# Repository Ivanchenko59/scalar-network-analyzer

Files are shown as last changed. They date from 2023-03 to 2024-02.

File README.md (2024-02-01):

# scalar-network-analyzer

## Description
This project was created as my graduating project at the university.
Scalar network analyzer developed to measure frequency response of filters, amplifiers, transmission lines or other frequency-dependent circuits.

## About the project

## Demo video

## Block scheme 

The basic principle of operation of a scalar analyzer is to measure the amplitude of a transmission wave through a device under test (DUT). 
Such an analyzer contains both a signal source and a receiver. The source is used to obtain a known signal, while the receiver is used to 
determine changes in this signal caused by the circuit under test.

зображення

The main component of the device is a signal generator SI5351 with 2 independent outputs, which has a square wave output signal, so it is 
impossible to use such a signal in a circuit with a broadband detector. So this was solved by using the architecture of a superheterodyne receiver.

The basic idea of a superheterodyne is a linear transfer of the spectrum to a specific frequency. This is achieved by synchronously changing the 
RF frequency (which is fed to the DUT) and the local oscillator (LO) frequency.

Next, the signal is filtered using piezoceramic filters at 455 kHz (this frequency was chosen because there are many cheap filters for this frequency) 
and amplified to use the full dynamic range of the logarithmic amplifier. After filtration, the signal will have a sinusoidal waveform.

The signal is fed to a logarithmic amplifier, the output of which is a constant voltage proportional to the power in dBm. The signal is then measured using an ADC
controller, processed with MCU and transmitted data to a computer via USB.

## Schematic

зображення

зображення

зображення

зображення

зображення

## Hardware
A 4-layer printed circuit board was designed and manufactured. I created two impedance profiles of 90 ohms for the USB interface and 50 ohms for high-frequency 
signal transmission lines, since the device must operate in systems with such wave impedance.

зображення

зображення

зображення

## Software
### CubeMX Connectivity 


## PC Application

## Testing
The low-pass at 12 MHz LC filter was tested. The ideal characteristic in LTSpice is shown below.

зображення

Measured characteristic with the use of the scalar analyzer is shown below. 

зображення

Also, an 8 MHz quartz resonator was measured.

зображення

Below is a characteristic of a piezoceramic bandpass filter with unknown characteristics (similar to the one used in the device circuitry).
It should be added that the impedance of the filter (1500 ohms) is not matched to the device (50 ohms), which causes noticeable ripples in the passband.

зображення

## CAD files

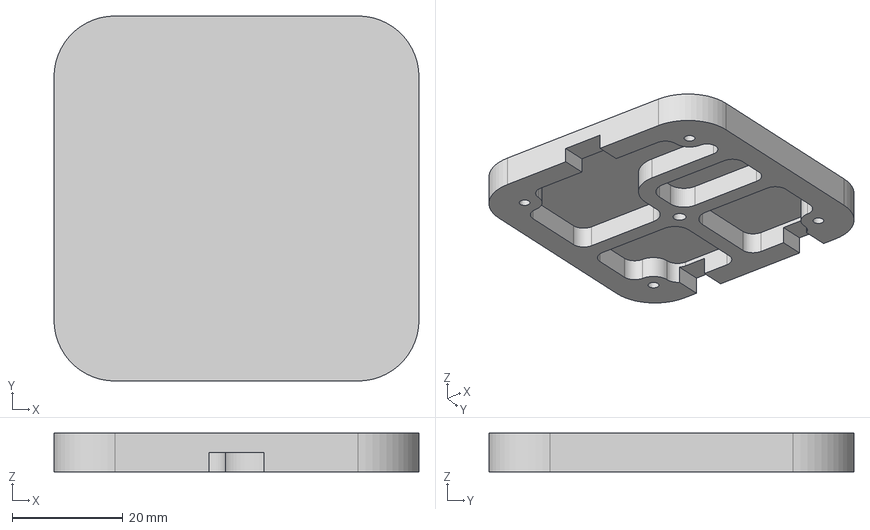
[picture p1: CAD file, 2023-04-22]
3dmodel/Top case.step
66.0 x 66.0 x 7.00 mm

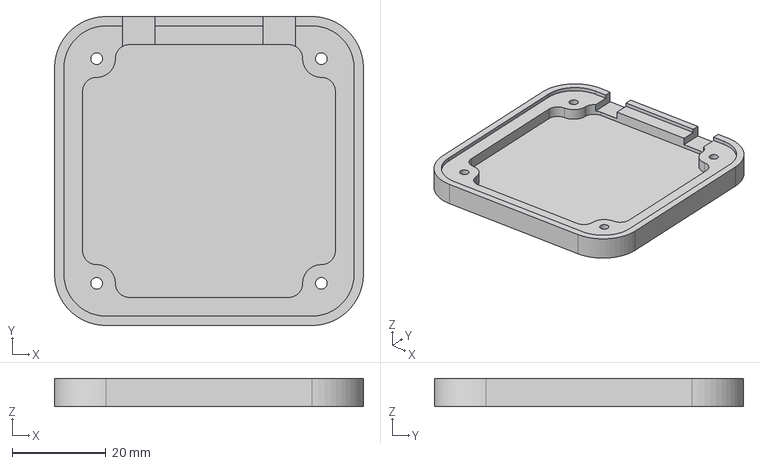
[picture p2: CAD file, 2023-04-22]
3dmodel/Bottom case.step
66.0 x 66.0 x 6.00 mm

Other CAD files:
3dmodel/Bottom case.f3d
3dmodel/Top case.f3d

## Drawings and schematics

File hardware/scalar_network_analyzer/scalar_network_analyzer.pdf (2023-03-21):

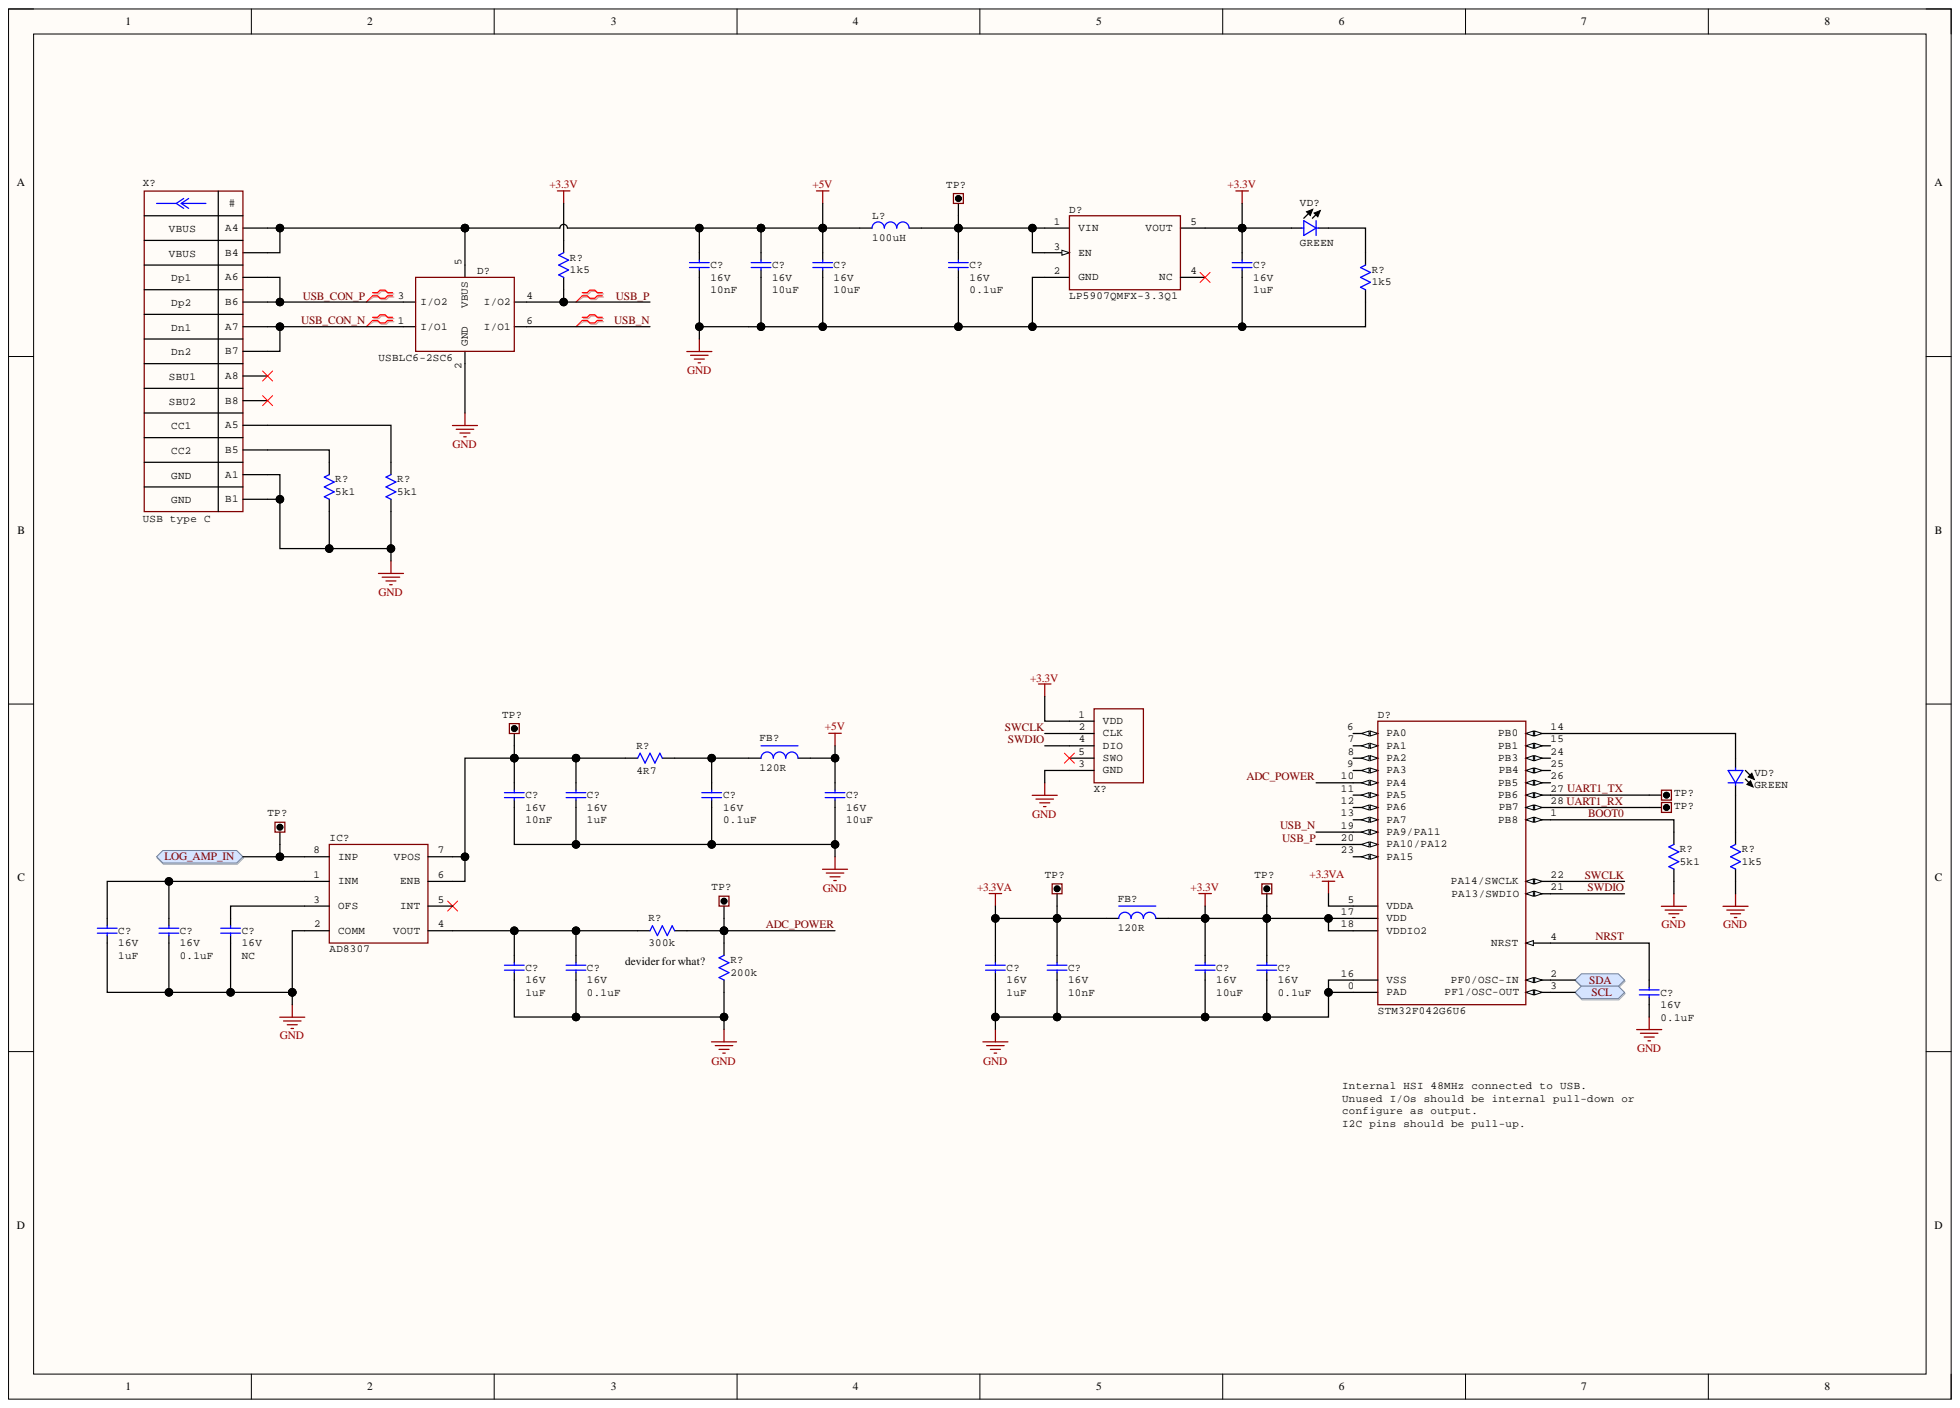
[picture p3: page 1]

VBUS | B4

SBU1 | A8

SBU2 | B8

GND | A1

GND | B1

Internal HSI 48MHz connected to USB.
Unused I/Os should be internal pull-down or
configure as output.
I2C pins should be pull-up.

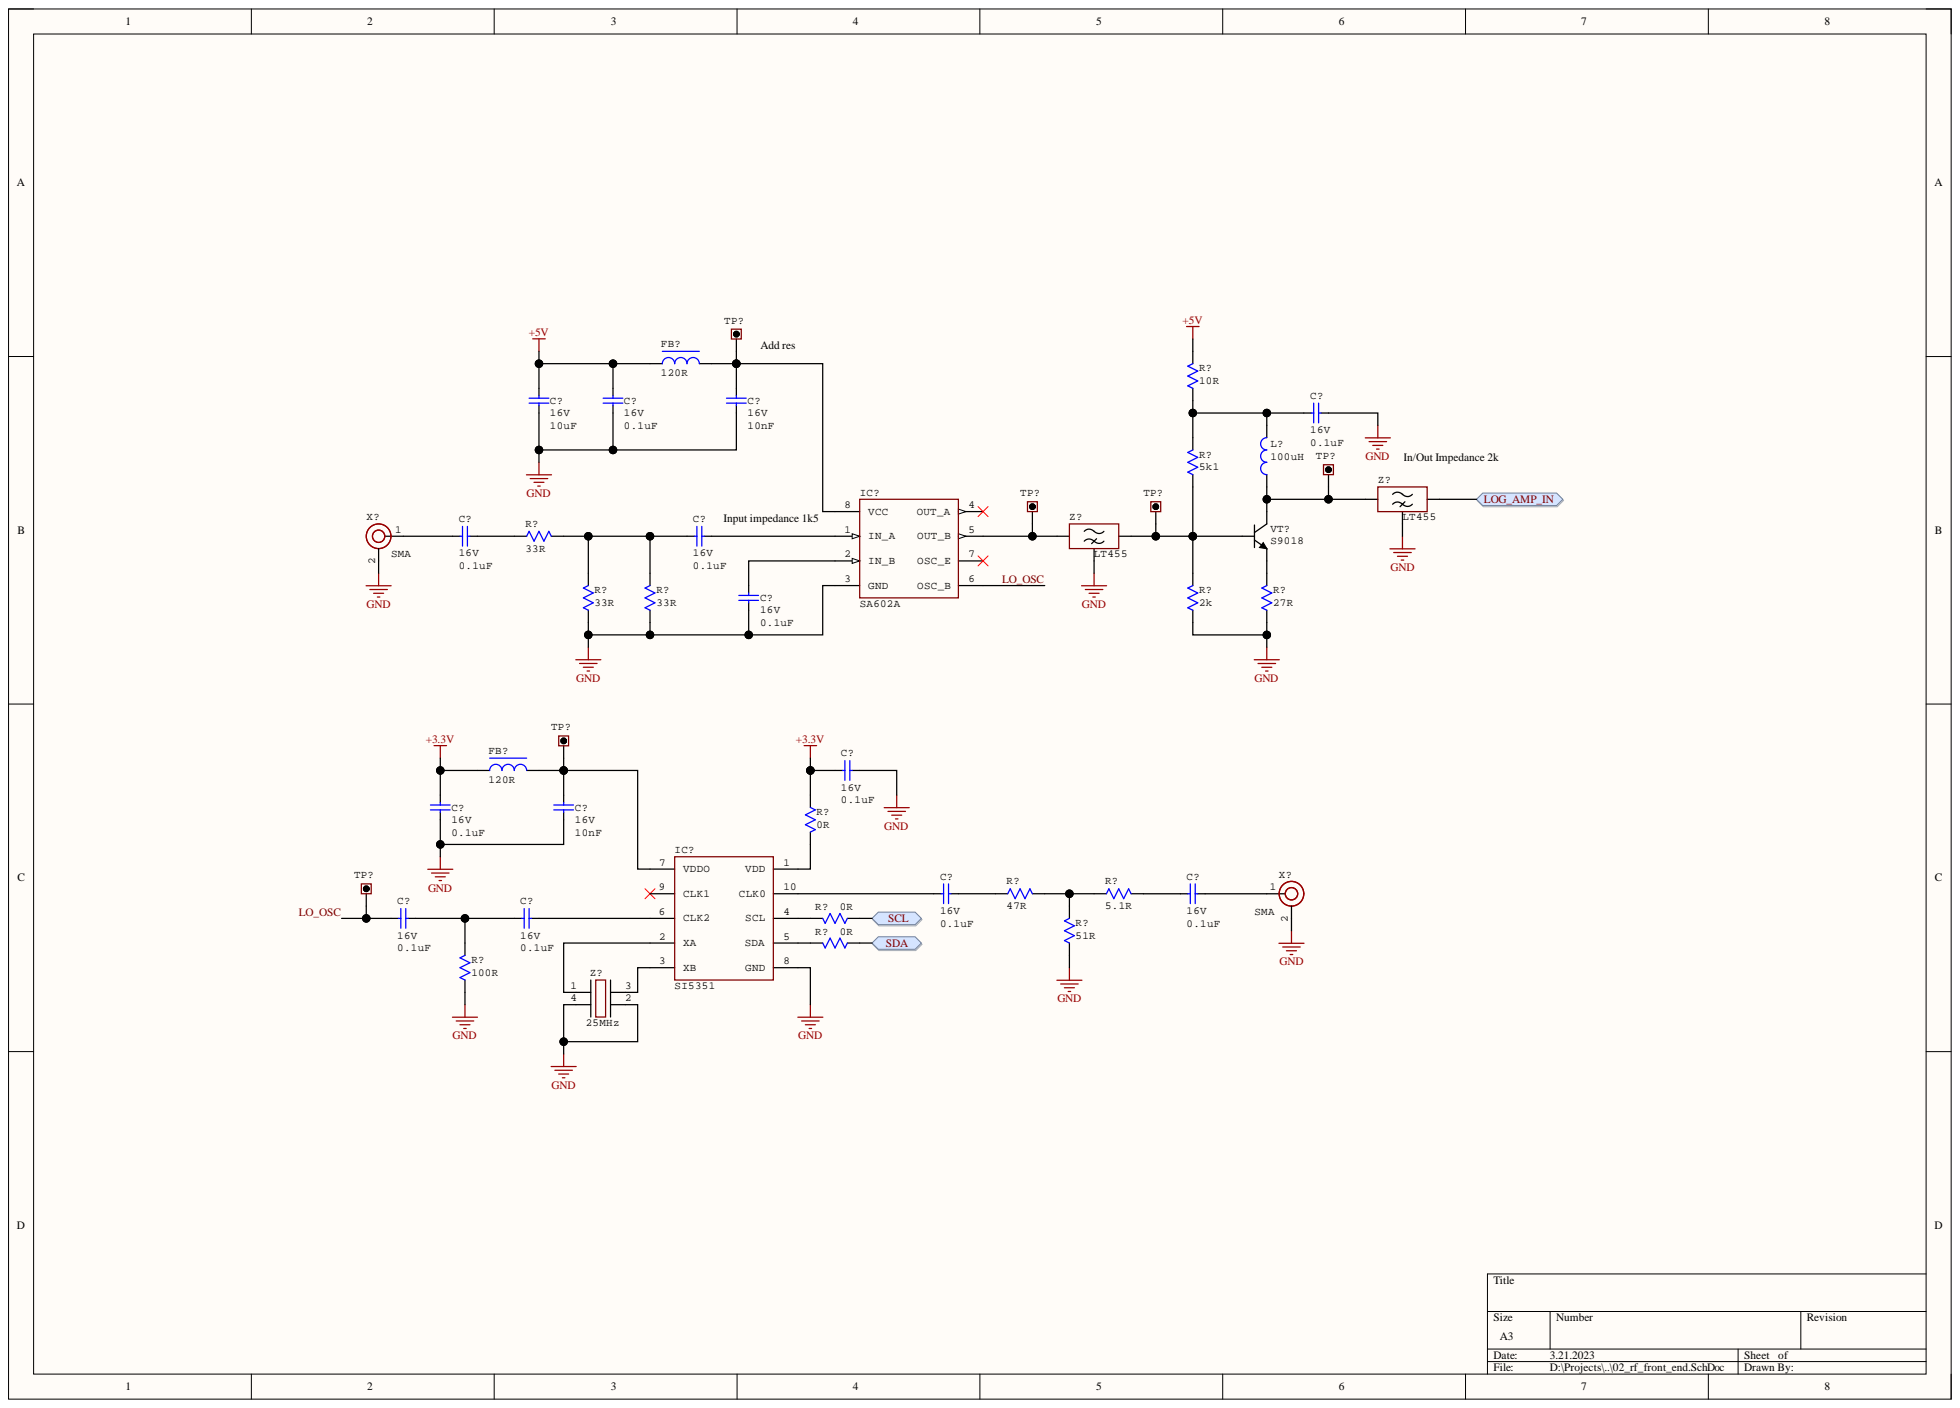
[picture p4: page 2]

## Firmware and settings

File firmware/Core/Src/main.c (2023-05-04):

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
/* Includes ------------------------------------------------------------------*/
#include "main.h"
#include "adc.h"
#include "dma.h"
#include "i2c.h"
#include "usart.h"
#include "usb_device.h"
#include "gpio.h"

/* USER CODE BEGIN Includes */
#include "usbd_cdc_if.h"
#include "si5351.h"

#include "device.h"
/* USER CODE END Includes */

/* USER CODE BEGIN PD */
#define VREFINT_CAL_ADDR	0x1FFFF7BA
#define VREFINT_CAL ((uint16_t*) VREFINT_CAL_ADDR)
/* USER CODE END PD */


/* USER CODE BEGIN PV */
const int32_t correction = 0;
volatile uint32_t new_time = 0;

//volatile uint32_t Vdd = 0;
/* USER CODE END PV */

void SystemClock_Config(void);
/**
  * @brief  The application entry point.
  * @retval int
  */
int main(void)
{
  /* MCU Configuration--------------------------------------------------------*/

  /* Reset of all peripherals, Initializes the Flash interface and the Systick. */
  HAL_Init();

  /* Configure the system clock */
  SystemClock_Config();

  /* Initialize all configured peripherals */
  MX_GPIO_Init();
  MX_I2C1_Init();
  MX_USB_DEVICE_Init();
  MX_USART1_UART_Init();
  MX_DMA_Init();
  MX_ADC_Init();
  /* USER CODE BEGIN 2 */
  HAL_ADCEx_Calibration_Start(&hadc);

  si5351_Init(correction);
  si5351_SetupCLK0(0, SI5351_DRIVE_STRENGTH_2MA);
  si5351_SetupCLK2(0, SI5351_DRIVE_STRENGTH_2MA);
  si5351_EnableOutputs((1 << 0) | (1 << 2));

  /* USER CODE END 2 */

  /* Infinite loop */
  /* USER CODE BEGIN WHILE */
  while (1)
  {
//	  Vdd = 3300 * (*VREFINT_CAL)/adc[1];

	  usb_command_parser();

	  if (HAL_GetTick() - new_time > 500) {
		  HAL_GPIO_TogglePin(GPIOB, GPIO_PIN_3);
		  new_time = HAL_GetTick();
	  }

    /* USER CODE END WHILE */

    /* USER CODE BEGIN 3 */
  }
  /* USER CODE END 3 */
}

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


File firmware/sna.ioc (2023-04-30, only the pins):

Mcu.UserName=STM32F042G6Ux
PA11.Signal=USB_DM
PA12.Signal=USB_DP
PA13.Signal=SYS_SWDIO
PA14.Signal=SYS_SWCLK
PA7.Signal=ADC_IN7
PB3.Signal=GPIO_Output
PB6.Signal=USART1_TX
PB7.Signal=USART1_RX
PF0-OSC_IN.Signal=I2C1_SDA
PF1-OSC_OUT.Signal=I2C1_SCL

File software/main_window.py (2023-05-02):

from PySide6.QtWidgets import (
    QComboBox,
    QFrame,
    QMainWindow,
    QPushButton,
    QWidget,
    QHBoxLayout,
    QVBoxLayout,
    QGroupBox,
    QLabel,
    QSpinBox,
    QDoubleSpinBox,
    QSizePolicy,
    QDialog,
    QCheckBox,
)
import pyqtgraph as pg
from datatypes import PointType 

from utils import convert_MHz_to_Hz, convert_Hz_to_MHz, convert_points_to_freq_step, convert_freq_step_to_points


class AnalyzerScreen(pg.PlotWidget):
    def __init__(self, parent=None, plotItem=None, **kargs):
        super().__init__(parent=parent, background="w", plotItem=plotItem, **kargs)
        
        self.plot_map = {}

        styles = {"color": "k", "font-size": "14px"}
        self.setLabel("left", "dB", **styles)
        self.setLabel("bottom", "Frequency", **styles)

        self.showGrid(x=True, y=True)
        self.setXRange(0, 450000000, padding=0.02)
        self.setYRange(-70, 0, padding=0.02)
        self.setLimits(xMin=-0.1, xMax=450000000)
        self.setLimits(yMin=-100, yMax=20)

        self.pen_ch = pg.mkPen(color="b", width=1.5)

    def plot_ch(self, x, y, plot_name='default', pen1=None):
        if pen1 is None:
            pen1 = self.pen_ch
        self.plot_map[plot_name] = self.plot(x, y, pen=pen1)
    
    def clear_ch(self, plot_name='default'):
        if plot_name in self.plot_map:
            self.plot_map[plot_name].clear()

    def set_axis(self, min, max):
        self.setLimits(xMin=min, xMax=max)
        self.setXRange(min, max, padding=0.02)
        pass


class SpinBox(QGroupBox):
    def __init__(self, controller, analyzer_screen, parent=None):
        super().__init__("Frequency", parent=parent)
        self.controller = controller
        self.analyzer_screen = analyzer_screen

        layout = QVBoxLayout()
        self.setLayout(layout)

        min_freq_layout = QHBoxLayout()
        min_freq_label = QLabel("Min (MHz):")
        self.spinbox_min_freq = QDoubleSpinBox()
        self.spinbox_min_freq.setDecimals(3)
        self.spinbox_min_freq.setRange(
            convert_Hz_to_MHz(self.controller.get_min_freq_in_Hz()), 
            convert_Hz_to_MHz(self.controller.get_max_freq_in_Hz())
        )
        self.spinbox_min_freq.setValue(convert_Hz_to_MHz(self.controller.get_min_freq_in_Hz()))
        min_freq_layout.addWidget(min_freq_label)
        min_freq_layout.addWidget(self.spinbox_min_freq)

        max_freq_layout = QHBoxLayout()
        max_freq_label = QLabel("Max(MHz):")
        self.spinbox_max_freq = QDoubleSpinBox()
        self.spinbox_max_freq.setDecimals(3)
        self.spinbox_max_freq.setRange(
            convert_Hz_to_MHz(self.controller.get_min_freq_in_Hz()), 
            convert_Hz_to_MHz(self.controller.get_max_freq_in_Hz())
        )
        self.spinbox_max_freq.setValue(convert_Hz_to_MHz(self.controller.get_max_freq_in_Hz()))
        max_freq_layout.addWidget(max_freq_label)
        max_freq_layout.addWidget(self.spinbox_max_freq)

        step_freq_layout = QHBoxLayout()
        step_freq_label = QLabel("Points:")
        self.spinbox_step_freq = QSpinBox()
        self.spinbox_step_freq.setRange(1, 10000)
        self.spinbox_step_freq.setValue(
            convert_freq_step_to_points(self.controller.get_min_freq_in_Hz(),
                                        self.controller.get_max_freq_in_Hz(),
                                        self.controller.get_step_freq()
            )
        )
                                        
        step_freq_layout.addWidget(step_freq_label)
        step_freq_layout.addWidget(self.spinbox_step_freq)

        layout.addLayout(min_freq_layout)
        layout.addLayout(max_freq_layout)
        layout.addLayout(step_freq_layout)

        self.spinbox_min_freq.editingFinished.connect(self.on_spinbox_min_freq_editing_finished)
        self.spinbox_max_freq.editingFinished.connect(self.on_spinbox_max_freq_editing_finished)
        self.spinbox_step_freq.editingFinished.connect(self.on_spinbox_step_freq_editing_finished)

    def on_spinbox_min_freq_editing_finished(self):
        value = convert_MHz_to_Hz(self.spinbox_min_freq.value())
        self.controller.set_min_freq(value)
        self.analyzer_screen.set_axis(value, self.controller.get_max_freq_in_Hz())

    def on_spinbox_max_freq_editing_finished(self):
        value = convert_MHz_to_Hz(self.spinbox_max_freq.value())
        self.controller.set_max_freq(value)
        self.analyzer_screen.set_axis(self.controller.get_min_freq_in_Hz(), value)

    def on_spinbox_step_freq_editing_finished(self):
        value = self.spinbox_step_freq.value()
        self.controller.set_step_freq(
            convert_points_to_freq_step(self.controller.get_min_freq_in_Hz(),
                                        self.controller.get_max_freq_in_Hz(),
                                        value
            )
        )


class CalibrationBox(QGroupBox):
    def __init__(self, controller, parent=None):
        super().__init__("Calibration", parent=parent)
        self.controller = controller

        layout = QHBoxLayout()
        self.setLayout(layout)

        self.button_calibrate = QPushButton("Calibrate")

        layout.addWidget(self.button_calibrate)

        self.button_calibrate.clicked.connect(self.on_calibrate_button)

    def on_calibrate_button(self):
        self.controller.analyzer_calibration_mode()
        print("Calibrated")


class AcquisitionBox(QGroupBox):
    def __init__(self, controller, parent=None):
        super().__init__("Acquisition", parent=parent)
        self.controller = controller

        self.is_running = False

        layout = QHBoxLayout()
        self.setLayout(layout)

        self.button_single = QPushButton("SINGLE")
        self.button_run = QPushButton("RUN")

        layout.addWidget(self.button_single)
        layout.addWidget(self.button_run)

        self.button_run.clicked.connect(self.on_run_stop_button)
        self.button_single.clicked.connect(self.on_single_button)

    def on_single_button(self):
        self.controller.analyzer_single_run()
        self.is_running = False
        self.button_run.setText("RUN")

    def on_run_stop_button(self):
        if self.is_running:
            self.controller.analyzer_stop()
            self.is_running = False
            self.button_run.setText("RUN")
        else:
            if self.controller.analyzer_continuous_run():
                self.is_running = True
                self.button_run.setText("STOP")
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

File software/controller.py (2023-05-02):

from PySide6.QtCore import QMutex, QObject, QThread, QWaitCondition, Signal, Qt
from PySide6.QtWidgets import QApplication, QMessageBox, QProgressDialog
from main_window import MainWindow
from device import Device

import serial.tools.list_ports
import debugpy

import calibration as calib
from utils import filter_func

from datatypes import Data 
from datatypes import PointType 


class Controller:
    def __init__(self):

        # device
        self.device = Device()

        # gui
        self.app = QApplication([])
        self.main_window = MainWindow(controller=self)

        # acquisition thread
        self.continuous_acquisition = False
        self.worker_wait_condition = QWaitCondition()
        self.acquisition_worker = AcquisitionWorker(
            self.worker_wait_condition, device=self.device
        )
        self.acquisition_thread = QThread()
        self.acquisition_worker.moveToThread(self.acquisition_thread)
        self.acquisition_thread.started.connect(self.acquisition_worker.run)
        self.acquisition_worker.finished.connect(self.acquisition_thread.quit)
        # self.acquisition_worker.finished.connect(self.acquisition_thread.deleteLater)
        # self.acquisition_thread.finished.connect(self.acquisition_worker.deleteLater)
        self.acquisition_worker.data_ready.connect(self.data_ready_callback)
        self.acquisition_thread.start()

        # on app exit
        self.app.aboutToQuit.connect(self.on_app_exit)


    def run_app(self):
        self.main_window.show()
        return self.app.exec_()

    def on_app_exit(self):
        print("exiting")

    def get_ports_names(self):
        return [p.device for p in serial.tools.list_ports.comports()]

    def connect_to_device(self, port):
        if port == "":
            QMessageBox.about(
                self.main_window,
                "Connection failed",
                "Could not connect to device. No port is selected.",
            )
        elif port not in self.get_ports_names():
            QMessageBox.about(
                self.main_window,
                "Connection failed",
                f"Could not connect to device. Port {port} not available. Refresh and try again.",
            )
        else:
            self.device.connect(port)

    def disconnect_device(self):
        self.device.disconnect()

    def is_device_connected(self):
        return self.device.is_connected()

    def show_no_connection_message(self):
        QMessageBox.about(
            self.main_window,
            "Device not connected",
            "No device is connected. Connect a device first.",
        )

    def set_min_freq(self, min_freq):
        self.device.min_freq = min_freq

    def set_max_freq(self, max_freq):
        self.device.max_freq = max_freq

    def set_step_freq(self, step_freq):
        self.device.step_freq = step_freq

    def get_min_freq_in_Hz(self):
        return self.device.min_freq

    def get_max_freq_in_Hz(self):
        return self.device.max_freq

    def get_step_freq(self):
        return self.device.step_freq

    def measure_at_freq(self, frequency):
        self.device.measure_at_freq(frequency)

    def analyzer_single_run(self):
        if self.device.is_connected():
            self.continuous_acquisition = False
            self.device.clean_buffers()
            self.main_window.screen.clear_ch()
            self.worker_wait_condition.notify_one()
            return True
        else:
            self.show_no_connection_message()
            return False

    def analyzer_continuous_run(self):
        if self.device.is_connected():
            self.continuous_acquisition = True
            self.device.clean_buffers()
            # self.worker_wait_condition.notify_one()
            return True
        else:
            self.show_no_connection_message()
            return False

    def analyzer_calibration_mode(self):
        if self.device.is_connected():
            
            self.progress_dialog = QProgressDialog(
                "Calibrating...", "Cancel", 
                self.device.min_freq, self.device.max_freq, self.main_window
            )
            self.progress_dialog.setWindowTitle("Calibration Progress")
            self.progress_dialog.setWindowModality(Qt.WindowModal)
            self.progress_dialog.setCancelButton(None)
            self.progress_dialog.setAutoClose(True)
            self.progress_dialog.setAutoReset(True)
            self.progress_dialog.show()

            data = Data([], [], PointType.RAW)
            
            for freq in range(self.device.min_freq, self.device.max_freq + self.device.step_freq, self.device.step_freq):
                if self.progress_dialog.wasCanceled():
                    break
                self.progress_dialog.setValue(freq)
                QApplication.processEvents()
                
                data.frequency.append(freq)
                adc_data = self.device.measure_at_freq(freq)
                data.points.append(adc_data)

            data.points = filter_func(data.points)

            # Save data to JSON file
            calib.write_calibration_data(data)

            self.progress_dialog.close()
            return True
        else:
            self.show_no_connection_message()
            return False

    def analyzer_stop(self):
        self.continuous_acquisition = False

    def data_ready_callback(self): 
        self.raw_data = self.acquisition_worker.raw_data
        self.filtered_data = Data(self.raw_data.frequency[:], [], PointType.RAW)
        self.filtered_data.points = filter_func(self.acquisition_worker.raw_data.points)
        
        self.calibrated_data = calib.perform_calibration(self.filtered_data)
        
        self.main_window.screen.plot_ch(
            self.calibrated_data.frequency, self.calibrated_data.points
        )
        
        if self.continuous_acquisition == True:
            self.worker_wait_condition.notify_one()

class AcquisitionWorker(QObject):

    finished = Signal()
    data_ready = Signal()

    def __init__(self, wait_condition, device, parent=None):
        super().__init__(parent=parent)
        self.wait_condition = wait_condition
        self.device = device
        self.mutex = QMutex()

    def run(self):
        # debugpy.debug_this_thread()
        while True:
            self.mutex.lock()
            self.wait_condition.wait(self.mutex)
            self.mutex.unlock()
            
            self.raw_data = self.device.acquire_single()

            self.data_ready.emit()

        self.finished.emit()

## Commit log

2023-03-21 added Altium Project
    Schematic mostly done
    [01_digital_back_end.SchDoc, 02_rf_front_end.SchDoc, Schlib.SchLib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]
2023-03-22 changed filter footprint to smd
    [02_rf_front_end.SchDoc, Schlib.SchLib]
2023-03-26 added pcb
    [01_digital_back_end.SchDoc, 02_rf_front_end.SchDoc, Schlib.SchLib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]
2023-04-02 almost done pcb and schematic
    [01_digital_back_end.SchDoc, 02_rf_front_end.SchDoc, Schlib.SchLib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]
2023-04-04 finished designators placement
    [01_digital_back_end.SchDoc, 02_rf_front_end.SchDoc]
2023-04-04 fixed CFUK455 footprint mapping
    adjusted footprint for jlcpcb manufacturing
    added JLCPCB Part # parameter to BOM
    [01_digital_back_end.SchDoc, 02_rf_front_end.SchDoc, Schlib.SchLib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]
2023-04-06 fixed stm32 footprint
    generated gerber and pcb was ordered
    [01_digital_back_end.SchDoc, Schlib.SchLib, scalar_network_analyzer.PrjPcb]
2023-04-11 added calibration button functionality and writting data to the json file
2023-04-12 added calibration based on linear interpolation
2023-04-13 added documentation info to schematic
    [01_digital_back_end.SchDoc, 02_rf_front_end.SchDoc]
2023-04-22 added 3d model for the housing
    [Bottom case.f3d, Bottom case.step, Top case.f3d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]
2023-04-27 added Debug button for setting frequency by hand
2023-04-30 added adc measurement with DMA and buffer, added delay after fteq_set
2023-04-30 moved calibration function to the separate file
2023-04-30 fixed double convertation in the calibration file
    added plot checkboxes to debug window
    [calibration.py, controller.py, main_window.py]
2023-05-02 Entering a step in frequency was replaced by the number of points
    [calibration.py, controller.py, device.py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]
2023-05-02 added x axis autoscale
2023-05-04 moved device logic to the separate file

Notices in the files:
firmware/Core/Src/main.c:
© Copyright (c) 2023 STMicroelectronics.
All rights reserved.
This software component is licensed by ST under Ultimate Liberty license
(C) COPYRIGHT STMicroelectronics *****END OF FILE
